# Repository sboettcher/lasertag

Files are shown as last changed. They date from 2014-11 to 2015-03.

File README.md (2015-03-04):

#Project Lasertag

Repository for the [Wearable Computing Lab Course 2014](http://praktikum.ese.uni-freiburg.de/)  
University of Freiburg  

##0. TODO
3D-Druck:
- 6 Gehäuse + Deckel
- Westen-Master drucken
- Laser-Dioden Enclousure
- Korpus für Edison 
- Korpus für Arduino Tagger 

CAD: 
- Westen-Master CAD Design (Platine + Blutooth-Modul + Schaltregler + Akku)
- Laser-Dioden Enclousure
- Korpus für Edison 
- Korpus für Arduino Tagger

Weste:
- Bestellung bei ESE-Lehrstuhl abholen
- Bei Obi 5 Kugeln kaufen
- Westen mit Domes bestücken

Server:
- Fertigstellen + testen

Tagger Edison:
- Main Platine auf der alles Zusammenläuft (als Lochraster) fertigen
- Code Edison fertigstellen und testen
- I2C RFID Reader oder SPI-I2C Converter Arduino
- Sende- und Empfangs-MSP über I2C (Code + testen)
- Tagger zusammenbauen
- LED-Stripe mit Timer 
- Reichweite Wifi testen

Tagger Arduino:
- Wifi Modul auf SmartNet programmieren
- Verbindung zu Server testen
- Reichweite Wifi testen

Allgemein:
- Berechnen ob Strahlung gefährlich ist

Präsentation:
- Poster designen, drucken
- Dokumentieren (Bilder + Text)

###0.1 ToBuy für 2 Westen-Tagger-Sets:

- 12x MSP
- 1x HC-06 Bluetooth
- 2-3x RFID-Reader
- 4x Plastik-Kugel
- 2x Weste
- 4x Akku
- 5m Kabel für Domes
- Klettband
- 1x Edison inkl. kleines Breakout-Board
- 1-2x Abzugsschalter
- kleine Schrumpfschläuche
- 2x Ein-/Aus-Schalter

##1. Edison
###1.1 Image Installation and Preparation
Installation instructions for getting the Intel Edison to work with the **Mini** Breakout board and a pre-built Yocto image.  
Get the latest image and Edison drivers [here](https://communities.intel.com/docs/DOC-23242).  
You can also follow the steps [here](https://communities.intel.com/message/261922), these instructions are mostly based on that.  
~# indicates a command line instruction

1. Install the Edison on the breakout board.
2. Install the [FTDI drivers](http://www.ftdichip.com/Drivers/CDM/CDM%20v2.10.00%20WHQL%20Certified.exe) and Intel Edison drivers.
3. Plug in Edison via USB cables, both cables are needed. When plugging in for the first time, Windows will install the device drivers, which may take some time. When finished, the edison should appear in the Explorer and have a drive letter assigned to it.
4. Format the Edison drive as FAT32, if it is not already.
5. Download the latest image and extract it to the drive.
6. Use PuTTY to connect to the Edison. Serial connection, find out COM port via device manager (Ports/USB Serial Port), speed is 115200.
7. Press Enter until the login prompt appears (1-2 times).
8. Login as **root**.
9. ~# reboot ota  
This automatically flashes the previously loaded image to the Edison, while rebooting. May take a while.
10. Login again as **root**.
11. ~# configure_edison --name
12. ~# configure_edison --password
13. ~# systemctl disable network-gadget-init.service  
This keeps the USB device from loading as a network interface.
14. ~# configure_edison --wifi
15. ~# reboot

So far the standard WiFi configuration tool in step 14 has worked fine for me. After successful connection you can also log in via ssh. If not, try commenting the line **BindToDevice=usb0** in /lib/systemd/system/sshd.socket. Afterwards reload the systemd daemon:

    systemctl daemon-reload

and reboot.

###1.2 Package Repositories
The Edison has no pre-configured package repository. To have access to some basic programs, follow the instructions [here](http://alextgalileo.altervista.org/edison-package-repo-configuration-instructions.html).  
Afterwards you may install some basic packages, like:

    opkg install bash packagegroup-core-buildessential cmake vim git ...

To get some basic IO functionality in your code, install the mraa library [here](https://github.com/intel-iot-devkit/mraa) and the upm repository [here](https://github.com/intel-iot-devkit/upm).  

    echo "src mraa-upm http://iotdk.intel.com/repos/1.1/intelgalactic" > /etc/opkg/mraa-upm.conf
    opkg update
    opkg install libmraa0 upm

A table with pin mappings for the mraa library can be found [here](http://iotdk.intel.com/docs/master/mraa/edison.html).  

You might also have to clone the upm repo and install it from source to compile some of the code here.  
In the cloned upm repo:

    mkdir build
    cd build
    cmake .. -DCMAKE_INSTALL_PREFIX:PATH=/usr
    make

###1.3 Partition Size Problem
I had a problem where the root partition of the Edison was 100% full at some point. This was mostly due to a lot of system boot logs (>100MB) still saved in **/var/log/journal**.  
A good fix for this would be to increase the size of the root partition (standard is 500MB), which is possible, but requires to rebuild the image, by hand, from scratch, and then re-flashing the Edison.  
What I ended up doing was simply limiting the size of the kept logs, after deleting all current saved logs.  

    rm -rf /var/log/journal/*
    sed -i '$a SystemMaxUse=25M' /etc/systemd/journald.conf

**Update:** Apparently limiting the maximum log size didn't work, I ran into the same problem again. I just deleted the logs again and changed the first line to

    Storage=none

No logs will be kept but the root partition won't fill up again. Might try to change this to *volatile*, which temporarily saves the current system log in /run/log/journal.

###1.4 Pin Mappings
Some important pin mappings for the project. Complete tables can be found [here](https://github.com/intel-iot-devkit/mraa/blob/master/docs/edison.md) and in the breakout board hardware guide (see dropbox).

| Edison Pin | Edison Function | Description | MRAA # |
|:---:|:---:|:---:|:---:|
| 19-1 | V_SYS | 3.15-4.5V input | 28 |
| 19-2 | V_OUT | 3.3V output | 29 |
| 19-3 | GND | GND | 30 |
| 17-10 | SPI-5-CS | Display CS | 9 |
| 17-11 | SPI-5-CLK | Display CLK | 10 |
| 17-12 | SPI-5-MOSI | Display SDI | 11 |
| 18-11 | SPI-5-MISO | | 24 |
| 19-5 | GPIO-46 | Display RST | 32 |
| 20-6 | GPIO-49 | Display RS | 47 |
| 18-13 | UART1-RX | BT Module TX  | 26 |
| 19-8 | UART1-TX | BT Module RX  | 35 |
| 17-7 | I2C-6-SCL | | 6 |
| 17-9 | I2C-6-SDA | | 8 |
| 18-6 | I2C-1-SCL | | 19 |
| 17-8 | I2C-1-SDA | | 7 |

TFT_22_ILI9225 pin mappings [here](https://github.com/Nkawu/TFT_22_ILI9225/wiki)

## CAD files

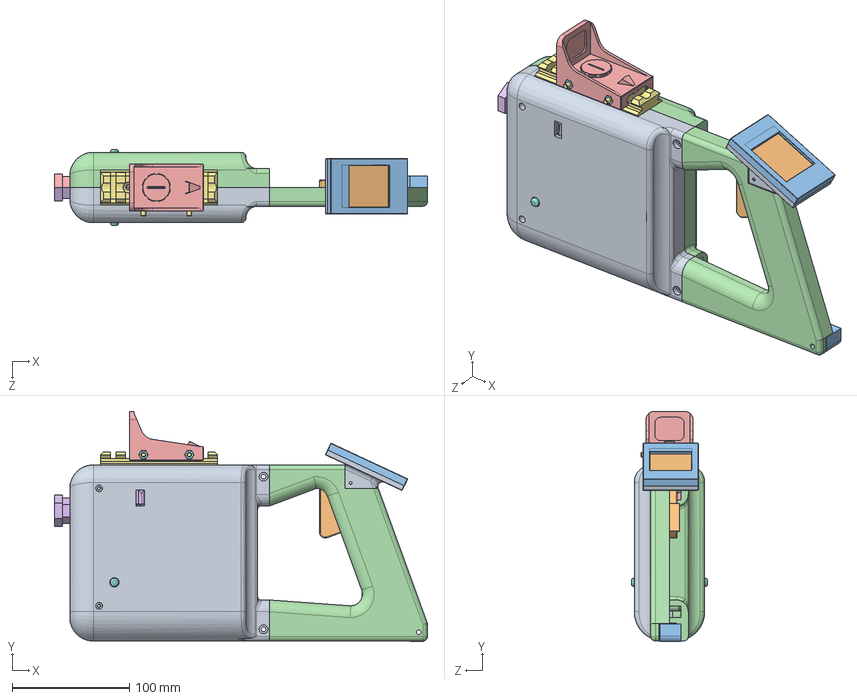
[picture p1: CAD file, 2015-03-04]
CADDesign/TotalAssembly.SLDASM
317.6 x 196.1 x 65.0 mm
Display_Holder_Single
Display_old x 2
DisplayLid x 2
Korpus
Rohr_u
Rohr_o
RailMount
Button x 2
KorpusL
Abzug
Griff_Akkuhalter
Griff_L
RedDot-Sight
IR_Receiver x 3
socket head cap screw_iso x 2
hex nut style 1 gradeab_iso x 2

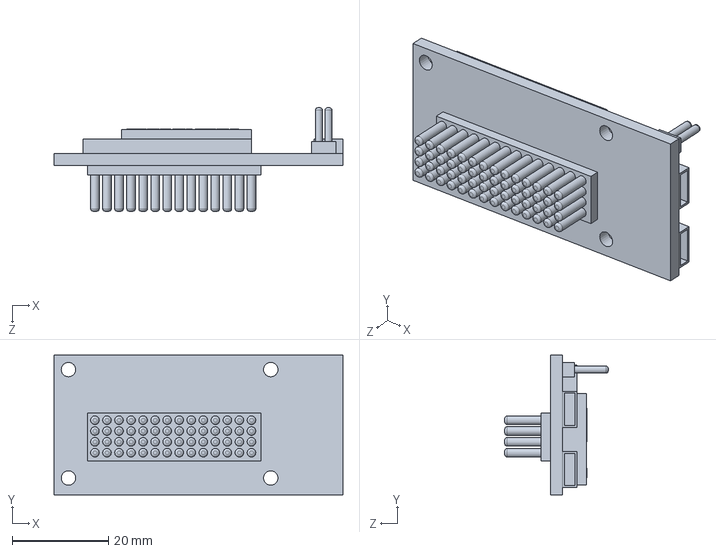
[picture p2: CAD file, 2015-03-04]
CADDesign/FinalDesigns/Components/Edison.SLDPRT
60.0 x 29.0 x 21.5 mm

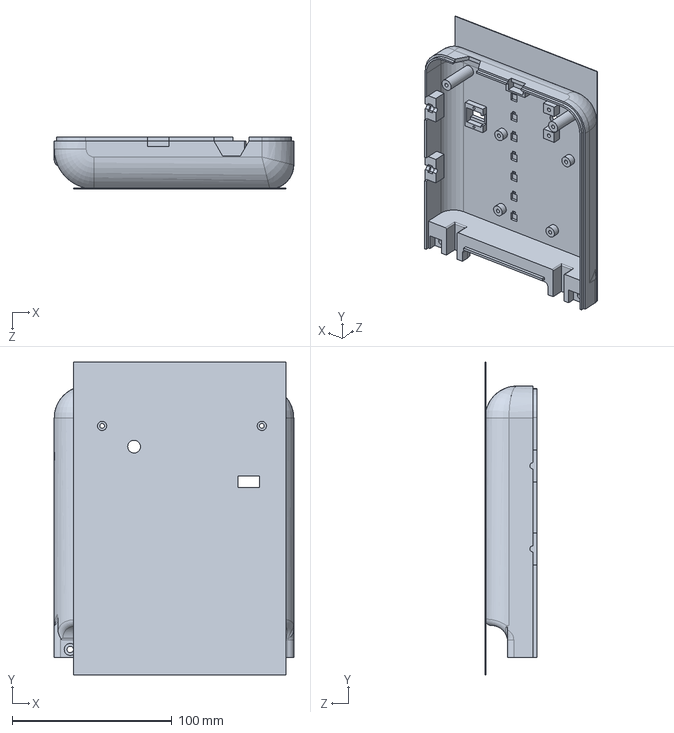
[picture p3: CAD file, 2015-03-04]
CADDesign/FinalDesigns/Corpus/KorpusLArduinoRaft.SLDPRT
150.0 x 196.0 x 32.5 mm

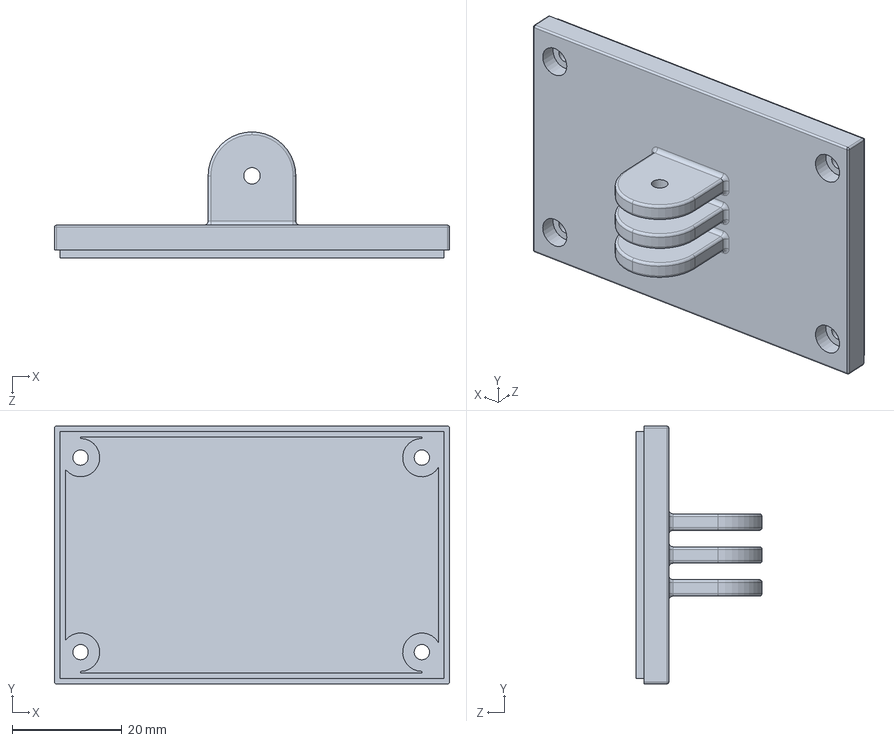
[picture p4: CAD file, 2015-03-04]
CADDesign/FinalDesigns/DisplayHolder/Display_Holder_with_Tripod.SLDPRT
72.0 x 47.0 x 23.0 mm

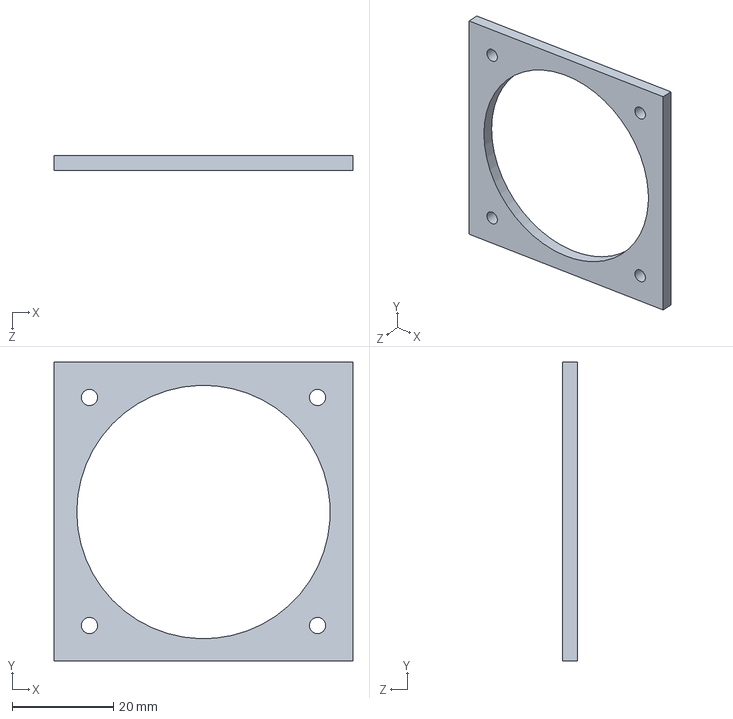
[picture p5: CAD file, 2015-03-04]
CADDesign/FinalDesigns/Domes/Deckel.SLDPRT
59.0 x 59.0 x 3.00 mm

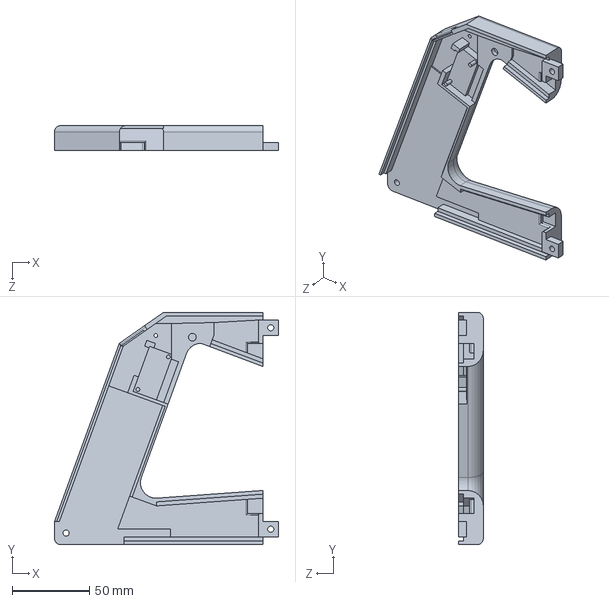
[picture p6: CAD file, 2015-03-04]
CADDesign/FinalDesigns/Handel/Griff_L_new.SLDPRT
144.6 x 150.0 x 16.0 mm

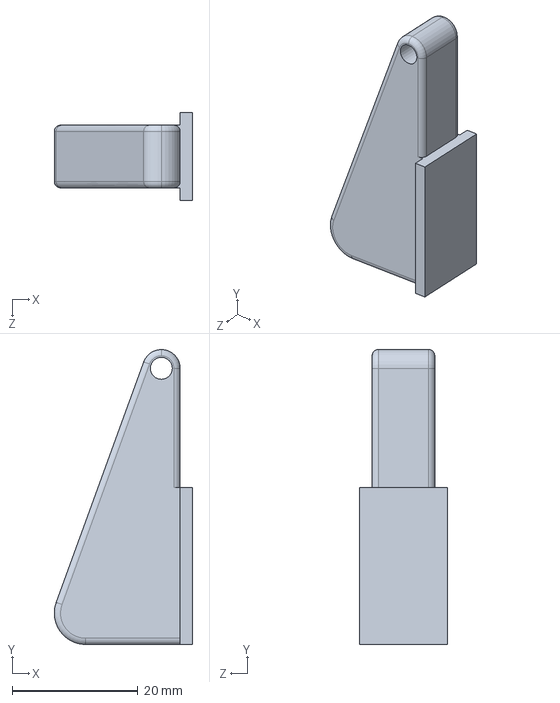
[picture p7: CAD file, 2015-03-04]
CADDesign/FinalDesigns/Other/Abzug.SLDPRT
22.1 x 47.0 x 14.0 mm

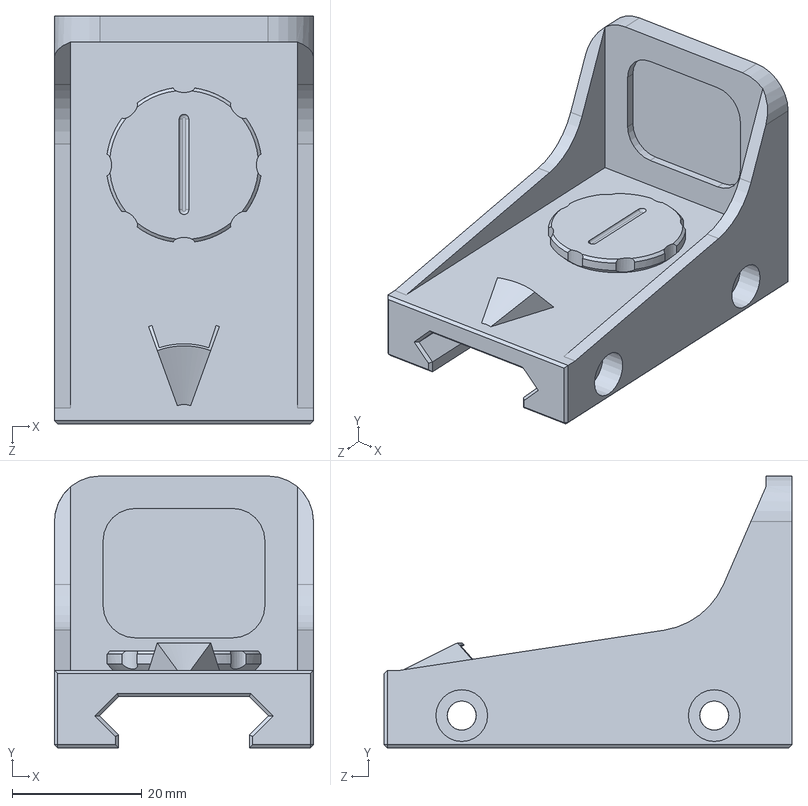
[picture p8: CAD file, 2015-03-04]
CADDesign/FinalDesigns/RailMount/RedDot-Sight.SLDPRT
40.0 x 42.0 x 63.0 mm

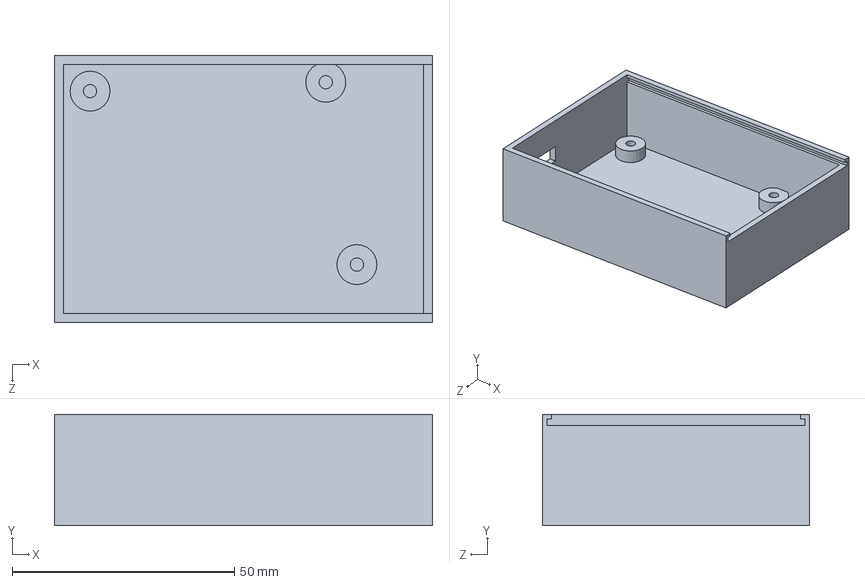
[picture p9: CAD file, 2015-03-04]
CADDesign/FinalDesigns/RFIDReader/Gehaeuse.SLDPRT
85.0 x 25.0 x 60.0 mm

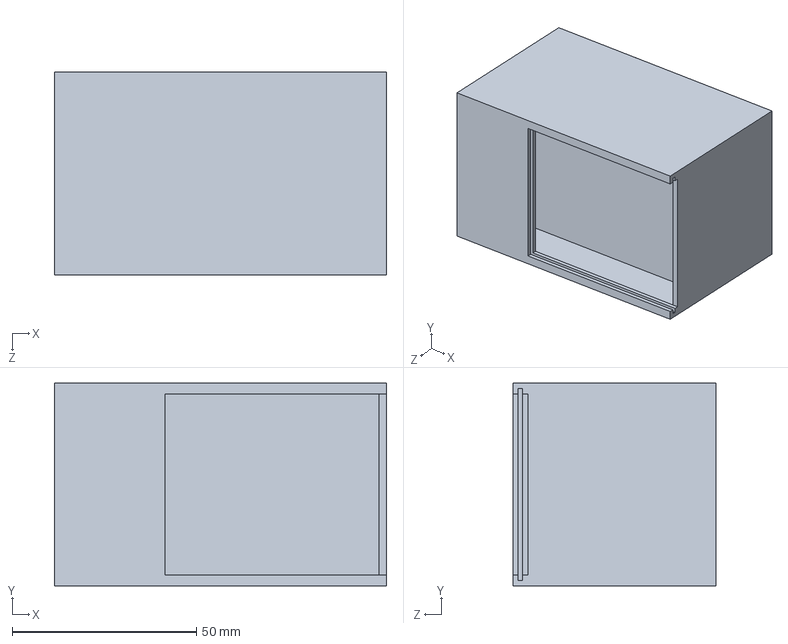
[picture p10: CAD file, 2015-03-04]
CADDesign/FinalDesigns/VestMaster/westMaster.SLDPRT
90.0 x 55.0 x 55.0 mm

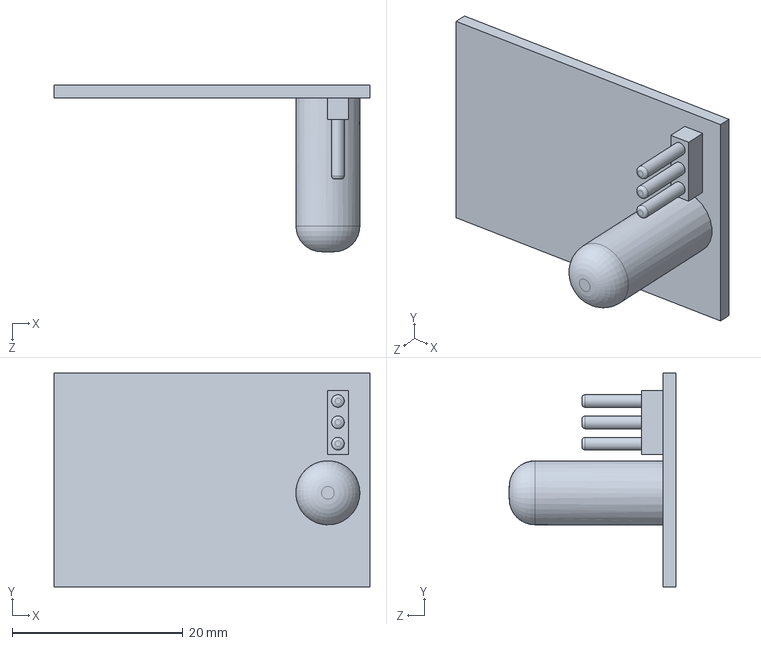
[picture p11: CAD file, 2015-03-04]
CADDesign/FinalDesigns/Components/Schaltregler.SLDPRT
37.0 x 25.0 x 19.5 mm

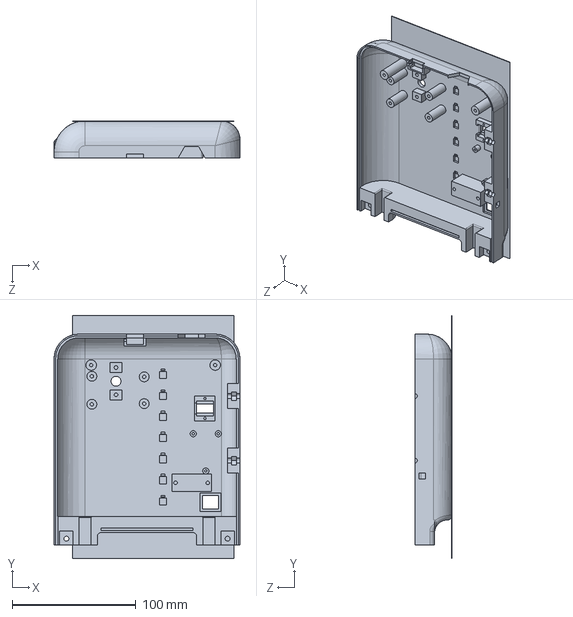
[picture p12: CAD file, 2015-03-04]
CADDesign/FinalDesigns/Corpus/KorpusREdison.SLDPRT
150.0 x 196.0 x 30.0 mm

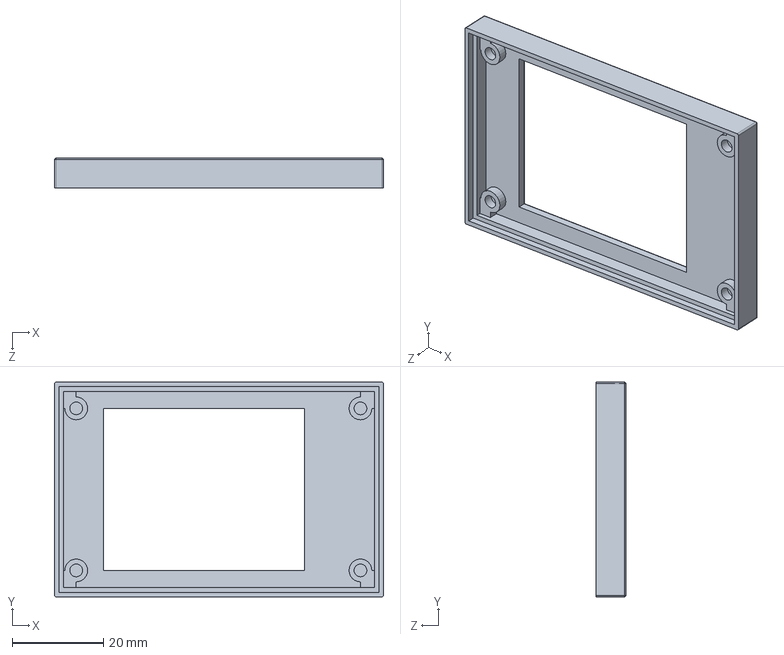
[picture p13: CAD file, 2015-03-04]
CADDesign/FinalDesigns/DisplayHolder/Display_Lid.SLDPRT
72.0 x 47.0 x 6.50 mm

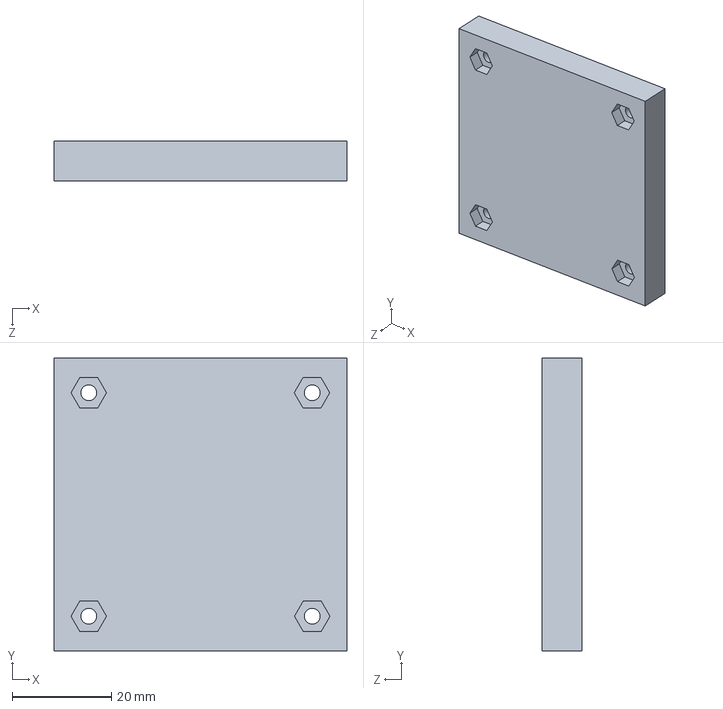
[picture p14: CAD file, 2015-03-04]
CADDesign/FinalDesigns/Domes/Gehäuse.SLDPRT
59.0 x 59.0 x 8.00 mm

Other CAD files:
CADDesign/FinalDesigns/Handel/Griff_Akkuhalter.SLDPRT
CADDesign/FinalDesigns/Other/Rohr.SLDPRT
CADDesign/FinalDesigns/RailMount/RedDot-Sight2.SLDPRT
CADDesign/FinalDesigns/RFIDReader/Deckel.SLDPRT
CADDesign/FinalDesigns/Components/Bluetooth_Tagger.SLDPRT
CADDesign/FinalDesigns/Components/Display.SLDPRT
CADDesign/FinalDesigns/Corpus/IRReceiver_Abdeckung.SLDPRT
CADDesign/FinalDesigns/Corpus/KorpusLEdison.SLDPRT
CADDesign/FinalDesigns/Corpus/KorpusRArduino.SLDPRT
CADDesign/FinalDesigns/DisplayHolder/Display_Holder_without_Tripod.SLDPRT
CADDesign/FinalDesigns/DisplayHolder/Display_Tripod.SLDPRT
CADDesign/FinalDesigns/Handel/Griff_R_new.SLDPRT
CADDesign/FinalDesigns/Other/Button.SLDPRT
CADDesign/FinalDesigns/RailMount/RailMountKabel.SLDPRT
CADDesign/FinalDesigns/RailMount/RedDot-Sight2_Bottom.SLDPRT
CADDesign/FinalDesigns/RailMount/RedDot-Sight2_Top.SLDPRT
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

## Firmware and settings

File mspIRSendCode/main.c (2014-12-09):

#include <msp430.h> 

// Turn on Debug modus over UART
#define DEBUG 1

// If not in Debug mode, no serial connection needed
#ifdef DEBUG
 #include "Serial.h"
#endif

// Time for one Bit
#define BITTIME 10000
// LSB (1) or MSB (0) first 
#define LSBFIRST 1
// The Speed of the UARRT connection
#define SERIALSPEED 9600
// The code that is send over IR
#define CODE 240
// Smallest delay between two transmissions 
#define DELAY_BETWEEN_TWO_SENDS 100000
// The clockSpeed in MHZ (CAUSION: needs to be changed in main as well)
#define CLK_SPEED 1
// The PWM frequency in kHz
#define PWM_FREQUZENCY 38
// The PWM periode
#define PWM_PERIODE (CLK_SPEED*1000.0/PWM_FREQUZENCY)

/*
 * main.c
 */


/*
 * Init the Ports
 */
void initPorts() {
	// Set LED1 to OUTPUT and to 0
	P1DIR |= BIT0;
	P1OUT &= ~BIT0;
	
	// Set Push Button to INPUT and enable PULLUPS
	P1DIR &= ~BIT3;
	P1REN |= BIT3;
	
	// Set IROutput PIN to Ouput and disable 
	P1DIR |= BIT6;
	// Set output source to timer A
	P1SEL |= BIT6;
	P1OUT &= ~BIT6;
	
	// PWM setup
	// Set the PWM periode to 38kHz
	TA0CCR0 = PWM_PERIODE;
	// Set dutyCycles to 50%
    TA0CCR1 = PWM_PERIODE/2;
    // Set output mode to resete/set
	TA0CCTL1 |= OUTMOD_7;
	// Set the counter to "count up" to TA0CCR0 with clock input "SMCLK"
	TA0CTL |= TASSEL_2 + MC_1;

}


/*
 * Sends a Code as a Byte by disabling and enabling PWM at the Port
 */
void sendCode(int Byte) {
	// Loop variable
	int i = 0;
	// Latch in Byte so it can be safely modified
	int code = 0;
	// Boolean used for parity check
	int parity = 0;
	if (LSBFIRST) {
		code = Byte;
	} else {
		code = ~Byte;
	}

	// Send start Bit
	P1SEL |= BIT6;
	_delay_cycles(BITTIME/2);

	if (DEBUG) serialPrintInt(1);
	
	// Loop over all Bits
	for (i = 0; i < 8; i++) {
		// If code and Mask not 0
		if ((code & BIT0) > 0) {
			// Send a logical 1
			P1SEL |= BIT6;
			if (DEBUG) serialPrintInt(1);
			// Xor of the Parity Bit
			parity ^= BIT0;
		} else {
			// Send a logical 0
			if (DEBUG) serialPrintInt(0);
			P1SEL &= ~BIT6;
			P1OUT &= ~BIT6;
		}
		// Shift the Bit to send
		code = code >> 1;
		// Wait a Bitlength
		_delay_cycles(BITTIME);
	}

	if (DEBUG) serialPrintInt(parity);
	// If it was an odd number of 1s
	if (parity) {
		// send parity 1
		P1SEL |= BIT6;
	} else {
		// else 0
		P1SEL &= ~BIT6;
		P1OUT &= ~BIT6;
	}
	// Send stop bit
	_delay_cycles(BITTIME);
	if (DEBUG) serialPrintInt(1);
	P1SEL |= BIT6;
	_delay_cycles(BITTIME);
	// Disable PWM on line
	P1SEL &= ~BIT6;
	P1OUT &= ~BIT6;
	if (DEBUG) serialPrintln("");
}


int main(void) {
	// Stop whatchdog
    WDTCTL = WDTPW + WDTHOLD;
	
	// Set clock to 1 MHz
	BCSCTL1 = CALBC1_1MHZ;
	DCOCTL = CALDCO_1MHZ;
	

    if (DEBUG) SerialBegin(SERIALSPEED, CLK_SPEED);
    
	// Init the Ports and the timers
    initPorts();

	if (DEBUG) {
		serialPrintln("Init Done!");
		serialPrint("CLK at: ");
		serialPrintInt(CLK_SPEED);
		serialPrintln(" MHz");
		serialPrint("PWM at: ");
		serialPrintInt(PWM_FREQUZENCY);
		serialPrintln(" kHz");
		serialPrint("Periode: ");
		serialPrintInt(PWM_PERIODE);
		serialPrintln(" clkCycles");
	}

	// Do forever and for always
    while(1) {
		// If Push Button pressed
    	if (!(P1IN & BIT3)) {
			// Send specifid Code
    		sendCode(CODE);
			// Display sending with LED on
			P1OUT |= BIT0;
			// Wait so that no Burst can be sended
    		_delay_cycles(DELAY_BETWEEN_TWO_SENDS);
		} else {
			// Turn LED off
			P1OUT &= ~BIT0;
		}
    }
}

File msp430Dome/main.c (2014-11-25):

#include <msp430.h> 
#include "laserTagIR.h"

#define DEBUG_UART 1
#ifdef DEBUG_UART
  #include "laserTagUART.h"
#endif

volatile char irInput = 0;
volatile char irBitCount = 0;
volatile int irDataBuffer = 0;
volatile char irParityCheck = 0;

void initClocks(void) {
  // Stop Watchdog Timer
  WDTCTL = WDTPW + WDTHOLD;

  // Init MCLK to 16 MHz
  if (CALBC1_1MHZ ==0xFF || CALDCO_1MHZ == 0xFF)
    while(1);
  BCSCTL1 = CALBC1_1MHZ;
  DCOCTL  = CALDCO_1MHZ;
}

void initIOPins(void) {
  P1SEL = 0x00;
  P1SEL2 = 0x00;
  // Set P1.x as input.
  P1DIR = 0x00 | BIT0;   // debugging led
  P1REN = 0x00;
  P1OUT = 0x00;
  // Enable interrupt on P1.6 on falling edge.
  IR_ENABLE_INTERRUPT


  #ifdef DEBUG_UART
    // Activate UART on 1.1 / 1.2
    // (fixed connection to PC, shows up there as COMx)
    P1SEL = BIT1 + BIT2;                      // P1.1 = RXD, P1.2=TXD
    P1SEL2 = BIT1 + BIT2;                     // P1.1 = RXD, P1.2=TXD
    UCA0CTL1 |= UCSSEL_2;                     // SMCLK
    UCA0BR0 = 104;                            // 1MHz 9600
    UCA0BR1 = 0;                              // 1MHz 9600
    UCA0MCTL = UCBRS0;                        // Modulation UCBRSx = 1
    UCA0CTL1 &= ~UCSWRST;                     // Initialize USCI state machine
    IE2 |= UCA0RXIE;                          // Enable USCI_A0 RX interrupt
    P1OUT = 0x00 | BIT0; // enable led1 in debug mode.
  #endif
}

/*
 * main.c
 */
int main(void) {
  initClocks();
  initIOPins();
  __enable_interrupt();

  #ifdef DEBUG_UART
    serialPrint("MSP430 booted!\n");
  #endif

  while (1) {
    // Check the parity and stop bit.
    // TODO(Jan): vielleicht direkt in der timer isr machen.
    if (irBitCount == IR_NUM_BITS) {
      if (irDataBuffer & IR_MASK_PARITY_STOP == IR_MASK_PARITY_STOP) { //TODO(Jan): tatsächlich auf parity checken!
        #ifdef DEBUG_UART
          serialPrint("Success! Received: ");
        #endif
      }
	#ifdef DEBUG_UART
  	  serialPrintInt(irDataBuffer);
  	  serialPrint("\n");
  	  irBitCount = 0;
	#endif
    }
  }
}

// Port1 isr.
#if defined(__TI_COMPILER_VERSION__) || defined(__IAR_SYSTEMS_ICC__)
  #pragma vector=PORT1_VECTOR
  __interrupt void PORT_1 (void) {
#elif defined(__GNUC__)
  void __attribute__ ((interrupt(PORT1_VECTOR))) PORT_1 (void)
#else
  #error Compiler not supported!
#endif
  // Falling edge on P1.6 -> start bit detected.
  if (P1IFG & BIT6) {
    IR_START_TIMER
    IR_DISABLE_INTERRUPT
    irBitCount = 0;
    irDataBuffer = 0;
    irParityCheck = 0;
  }
}


// Timer A0 interrupt service routine
#if defined(__TI_COMPILER_VERSION__) || defined(__IAR_SYSTEMS_ICC__)
  #pragma vector=TIMER0_A0_VECTOR
  __interrupt void Timer_A (void)
#elif defined(__GNUC__)
  void __attribute__ ((interrupt(TIMER0_A0_VECTOR))) Timer_A (void)
#else
  #error Compiler not supported!
#endif
  // Read ir input (active low).
  irInput = (~P1IN & BIT6) >> 6;

  // shift ir input into the buffer and count 1s for parity check.
  irDataBuffer = (irDataBuffer << 1) | irInput;
  irParityCheck += irInput;
  irBitCount++;

  // If transmission is complete, stop the timer and enable the P1.6 interrupt.
  // TODO(Jan): vielleicht interrutpt erst wieder aktivieren, wenn übertragung erfolgreich war.
  if (irBitCount == IR_NUM_BITS) {
    // Transmission finished. Stop timer and go back to idle state.
    IR_STOP_TIMER
    IR_ENABLE_INTERRUPT
  }
  
  TA0CCTL0 &= ~CCIFG;
}

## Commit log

2014-11-18 init commit for msp430Dome. receiver currently not working
    [main.c]
2014-11-25 modified timer and pin isr to support different compilers
2014-12-02 Added CAD design of tagger
    [Tagger.SLDPRT]
2014-12-10 bluetooth test works now; started lasertagMain, i2c test for now
2014-12-11 created a lasertag class, to be extended as needed; adjusted lasertagMain and Makefile accordingly
2014-12-16 added a constructor to specify i2c bus number; other related changes
2014-12-20 added new display to lasertag class + more minor stuff
2015-01-09 ILI9225: removed led backlight stuff since it doesn't work anyway
    [TFT_22_ILI9225.cpp]
2015-01-09 added a tcp client and communication with server to lasertagMain
2015-01-15 fixed a bug where bluetooth would connect to the wrong address; lasertagMain now includes bluetooth, i2c, tcp and display stuff; some other minor changes
2015-01-16 removed some obsolete stuff from lasertag class
2015-01-16 moved bluetooth and tcp to lasertag class; other stuff
2015-01-16 started adding some threading stuff
2015-01-18 more threading stuff; moved some functions to private
2015-01-18 replaced stuff in lasertagMain with threads from class, not tested yet; still missing display writing
    [lasertag.cpp]
2015-01-20 Current CAD-design files added to GIT.
    [DisplayAssambled.SLDASM, DisplayGriffFlat.SLDASM, DisplayLid.SLDPRT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]
2015-01-20 changed some stuff, done from memory since edison broke, needs to be tested
    [TFT_22_ILI9225.cpp, lasertag.cpp, lasertag.h]
2015-01-28 can now configure serial port baud rate; moved i2c init to function; other minor changes
2015-01-28 fixed member initialization list order
    [lasertag.cpp, lasertag.h]
2015-01-30 now fully using player class; spawn bt thread only when bt initialized; minor changes
2015-02-05 bt connection only gives lower case suddenly...; added some functions; smaller changes
2015-02-06 better bluetooth transmission parsing; not using gpio anymore, i2c from msp instead
2015-02-06 added a bunch of i2c functionality
2015-02-06 i2c defines; reset function; bugfixes; other stuff
    [lasertag.cpp, lasertag.h]
2015-02-07 more i2c stuff
2015-02-07 bugfixes; reenabling some i2c stuff; small changes
    [lasertag.cpp]
2015-02-07 bugfix, small changes, removed some dead code
    [lasertag.cpp]
2015-02-09 check for i2c success, other i2c stuff; other changes; final commit for now
2015-02-09 divide reset player to separate functions; bugfixes, other changes
    [lasertag.cpp, lasertag.h]
2015-02-12 doesn't exit when tcp connect fails, just continues without server functions
    [lasertag.cpp]
2015-02-15 Cleaned up the CAD design files and added the final designs.
    [Abzug.SLDPRT, Bluetooth_Tagger.SLDPRT, Button.SLDPRT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]
2015-02-15 Deleted final design due to changes.
    [Abzug.SLDPRT, Bluetooth_Tagger.SLDPRT, Button.SLDPRT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]
2015-02-15 Added final design with new better folder names.
    [Abzug.SLDPRT, Bluetooth_Tagger.SLDPRT, Button.SLDPRT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]
